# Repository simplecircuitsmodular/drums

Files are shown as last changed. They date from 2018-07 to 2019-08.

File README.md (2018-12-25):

# Drums

## Features
These modules features 6 individually triggered and tuned drum voices in one module. The code was written Jan Ostman. I have chosen to rehost the code here for other's convenience as Jan's hosting method introduced numerous endlines that prevented the code from compiling. Jan's source code can be found here:

[Western Drums, DSP-D8](https://janostman.wordpress.com/2016/01/03/the-dsp-d8-drumchip-source-code/)

[Latin Drums, DSP-L8](https://janostman.wordpress.com/2016/01/04/the-dsp-l8-latin-perc-source-code/)

## Files
### westernDrums_01.ino and latinDrums_01.ino
This is the Arduino code. An ISP header on the board allows the microcontroller to be programmed directly. The code was written by Jan Ostman. The Features section has links to Jan's source code.

### drums_xx.brd and .sch
These are the Eagle files for the PCB. To order PCBs, gerbers need to be generated using a CAM job in Eagle. A free version of Eagle is available that can do this. Both the latin and western drums use the same board, the only difference is the panel and code.

### drumsParts_xx.md
This is the parts list. A Mouser BOM is available at in this file as well.

### westernDrums.ai and latinDrums.ai
This is the panel in Adobe Illustrator format. This can be used to manufacture a panel, which I do with 1/8" acrylic and a laser cutter.

## Updates

### 01.1 30JUL18

Verified design. All functions work, though two issues were found. Added values to Eagle files for resistors and capacitors. Updated .brd to fix ISP issue, though this is currently untested. All signals were rerouted.

### 01 24JUN18
First push to GitHub. Currently this design is untested.

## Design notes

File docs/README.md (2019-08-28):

#### [Latin](#latin) | [Western](#western) | [Buy](#buy)

# Latin

### Overview

Based on the DSP-L8 drum voice chip, this module offers 8 polyphonic drum sounds in a small package. Featuring cabasa, agogo, timbale, whistle, quijada, maraca, congo, and chime sounds, each voice can be triggered individually and the maraca, chime, whistle, agogo, timbale, and quijada can be individually tuned.

### Design

Utilizing an ATMega 328 chip, this module can be easily programmed with the Arduino IDE and an ISP Programmer. A 7805 regulator removes the need for a 5v rail on your PSU, and as an all digital module the current draw is very low. The code used was written by Jan Osterman. I have chosen to rehost Jan's code as his hosting method causes numerous compilation errors.

# Western

### Overview 

Based on the DSP-8 drum voice chip, this module offers 8 polyphonic drum sounds in a small package. Featuring bass, open hat, closed hat, ride, rim shot, snare, clap, and crash sounds, each voice can be triggered individually, and the rim shot, clap, crash, snare, closed hat and open hat can be individually tuned.

### Design 

Utilizing an ATMega 328 chip, this module can be easily programmed with the Arduino IDE and an ISP Programmer. A 7805 regulator removes the need for a 5v rail on your PSU, and as an all digital module the current draw is very low. The code used was written by Jan Osterman. I have chosen to rehost Jan's code as his hosting method causes numerous compilation errors.

### Buy

I'll be updating this part soon with a link to buy PCBs on Reverb. For the time being you can email me to purchase development PCBs at a discount. These will be fully functional but have minor issues. In the case of the Drum PCBs, the programming header must be soldered to the front side of the PCB, meaning the front panel must be removed to program the module. In addition, the back of the board is missing silk screen.

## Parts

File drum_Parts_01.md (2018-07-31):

# Parts List

Mouser BOM: https://www.mouser.com/ProjectManager/ProjectDetail.aspx?AccessID=271197b1ba

| Name | Value | Package | Source |
| --- | --- | --- | --- |
| C1, 2, 6 | 10u | Radial TH | Mouser |
| C3, 4 | 22pf | Radial TH | Mouser |
| C5 | 100n | Radial TH | Mouser |
| IC1 | ATMega 328 | DIP-28 | Mouser |
| IC2 | 7805 | TO220H | Mouser |
| IC3 | TL072 | DIP8 | Mouser |
| R1-3 | 1k | Axial TH | Mouser |
| SV1 | 6 pin header | 2.54mm | Mouser |
| SV2 | 10 pin header | 2.54mm | Mouser |
| U$1-8, 15 | Switched mono jack | Thonkiconn | Modular Addict |
| U$9-14 | Potentiometer, B10k | Alpha 9mm vertical | Mouser |

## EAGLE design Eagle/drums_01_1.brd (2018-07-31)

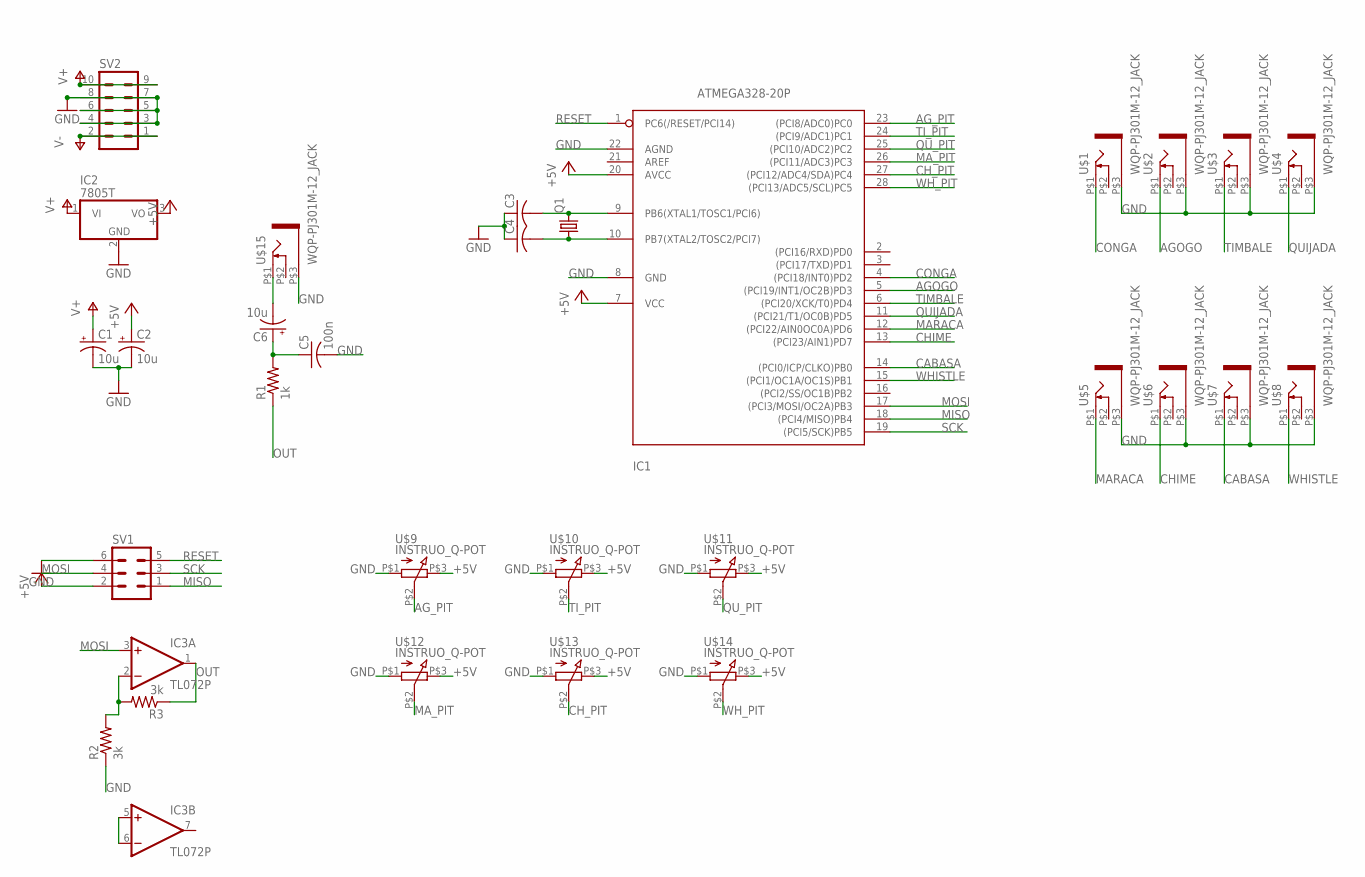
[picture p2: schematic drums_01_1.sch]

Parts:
C1, C2, C6: 10u; E2,5-6
C3, C4: C-US025-024X044; C025-024X044
C5: 100n; C025-024X044
IC1: ATMEGA328-20P; DIL28-3
IC2: 7805T; TO220H
IC3: TL072P; DIL08
Q1: CRYSTALHC49U-V; HC49U-V
R1: 1k; 0207/12
R2, R3: 3k; 0207/12
SV1: MA03-2
SV2: MA05-2
U$1, U$2, U$3, U$4, U$5, U$6, U$7, U$8, U$15: WQP-PJ301M-12_JACK
U$9, U$10, U$11, U$12, U$13, U$14: INSTRUO_Q-POT

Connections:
+5V: C2.+, IC1.7 (VCC), IC1.20 (AVCC), IC2.3 (VO), SV1.2, U$9.P$3 (3), U$10.P$3 (3), U$11.P$3 (3), U$12.P$3 (3), U$13.P$3 (3), U$14.P$3 (3)
AGOGO: IC1.5 ((PCI19/INT1/OC2B)PD3), U$2.P$1 (2)
AG_PIT: IC1.23 ((PCI8/ADC0)PC0), U$9.P$2 (2)
CABASA: IC1.14 ((PCI0/ICP/CLKO)PB0), U$7.P$1 (2)
CHIME: IC1.13 ((PCI23/AIN1)PD7), U$6.P$1 (2)
CH_PIT: IC1.27 ((PCI12/ADC4/SDA)PC4), U$13.P$2 (2)
CONGA: IC1.4 ((PCI18/INT0)PD2), U$1.P$1 (2)
GND: C1.-, C2.-, C3.1, C4.1, C5.2, IC1.8 (GND), IC1.22 (AGND), IC2.2 (GND), R2.1, SV1.6, SV2.3, SV2.4, SV2.5, SV2.6, SV2.7, SV2.8, U$1.P$3 (1), U$2.P$3 (1), U$3.P$3 (1), U$4.P$3 (1), U$5.P$3 (1), U$6.P$3 (1), U$7.P$3 (1), U$8.P$3 (1), U$9.P$1 (1), U$10.P$1 (1), U$11.P$1 (1), U$12.P$1 (1), U$13.P$1 (1), U$14.P$1 (1), U$15.P$3 (1)
MARACA: IC1.12 ((PCI22/AIN0OC0A)PD6), U$5.P$1 (2)
MA_PIT: IC1.26 ((PCI11/ADC3)PC3), U$12.P$2 (2)
MISO: IC1.18 ((PCI4/MISO)PB4), SV1.1
MOSI: IC1.17 ((PCI3/MOSI/OC2A)PB3), IC3.3 (+IN), SV1.4
unnamed: C3.2, IC1.9 (PB6(XTAL1/TOSC1/PCI6)), Q1.2
unnamed: C4.2, IC1.10 (PB7(XTAL2/TOSC2/PCI7)), Q1.1
unnamed: C6.-, U$15.P$1 (2)
unnamed: C5.1, C6.+, R1.2
unnamed: IC3.5 (+IN), IC3.6 (-IN)
unnamed: IC3.2 (-IN), R2.2, R3.2
OUT: IC3.1 (OUT), R1.1, R3.1
QUIJADA: IC1.11 ((PCI21/T1/OC0B)PD5), U$4.P$1 (2)
QU_PIT: IC1.25 ((PCI10/ADC2)PC2), U$11.P$2 (2)
RESET: IC1.1 (PC6(/RESET/PCI14)), SV1.5
SCK: IC1.19 ((PCI5/SCK)PB5), SV1.3
TIMBALE: IC1.6 ((PCI20/XCK/T0)PD4), U$3.P$1 (2)
TI_PIT: IC1.24 ((PCI9/ADC1)PC1), U$10.P$2 (2)
V+: C1.+, IC2.1 (VI), IC3.8 (V+), SV2.9, SV2.10
V-: IC3.4 (V-), SV2.1, SV2.2
WHISTLE: IC1.15 ((PCI1/OC1A/OC1S)PB1), U$8.P$1 (2)
WH_PIT: IC1.28 ((PCI13/ADC5/SCL)PC5), U$14.P$2 (2)

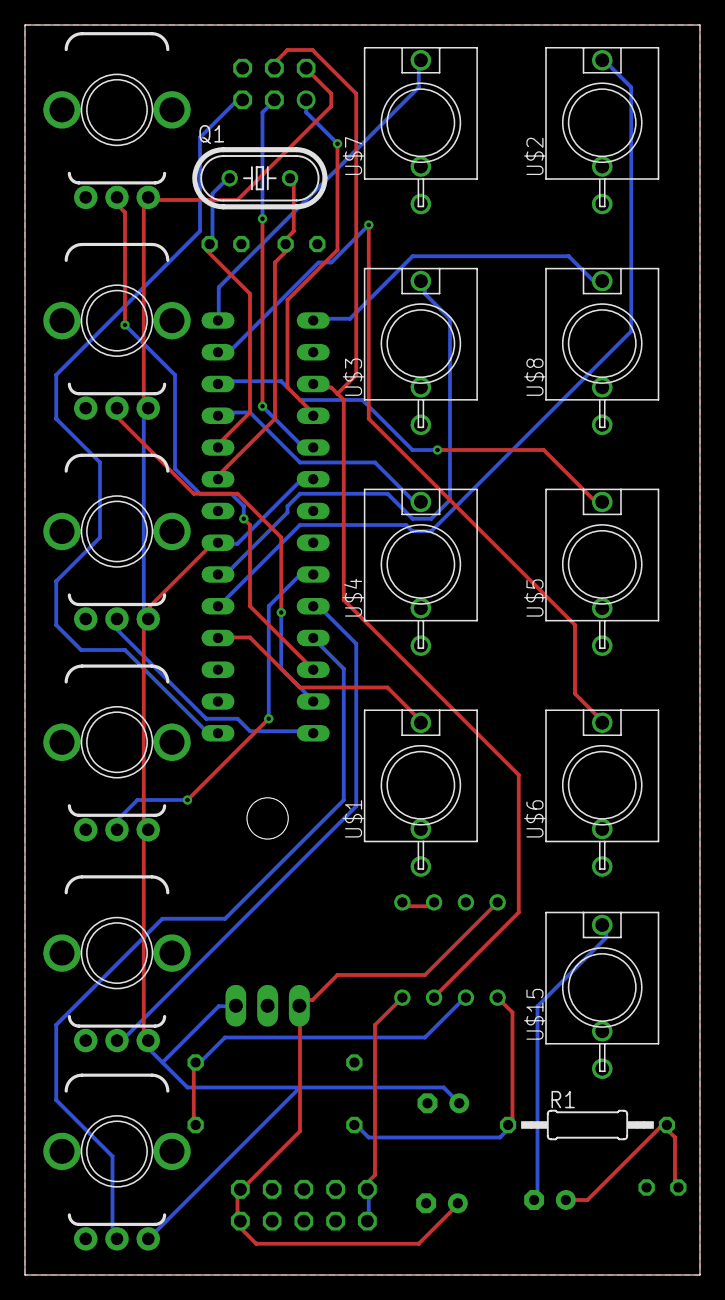
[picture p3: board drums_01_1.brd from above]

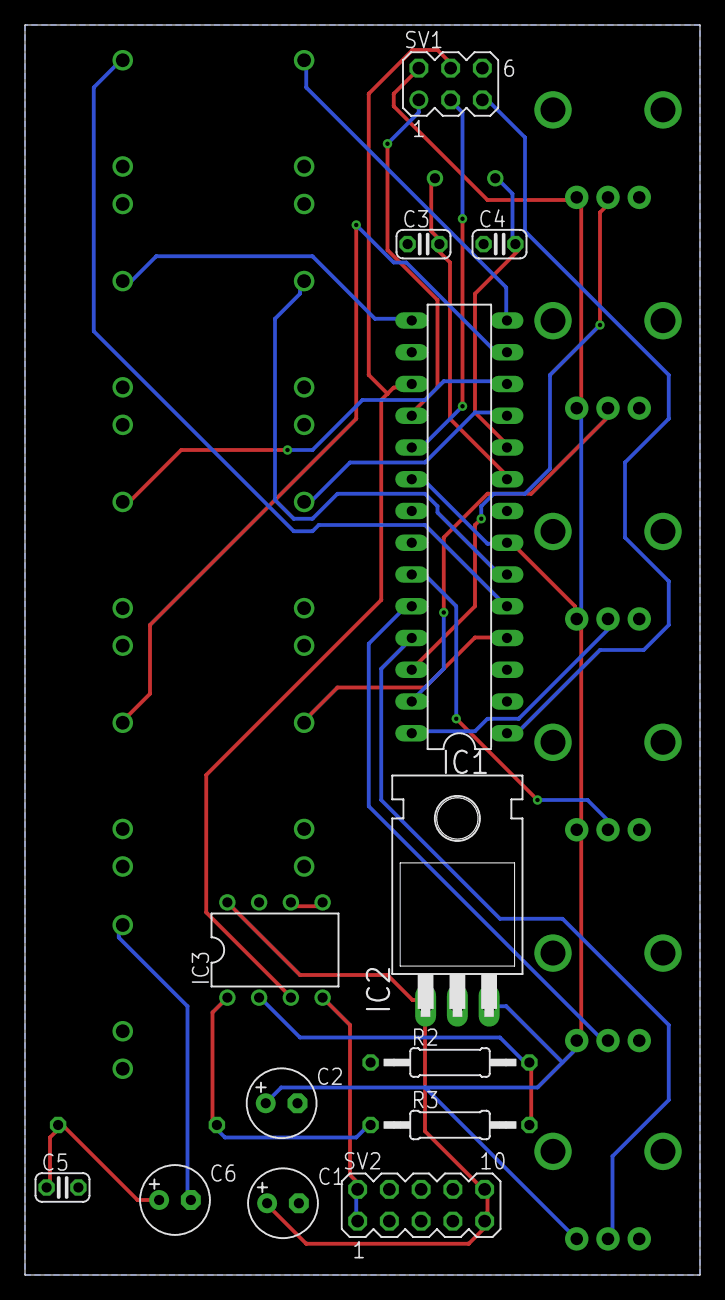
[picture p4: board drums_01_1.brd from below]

Board: 2 copper layers, 54.0 x 100.0 mm, 30 parts (13 on the bottom side), 29 nets.

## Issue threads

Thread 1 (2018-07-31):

Missing Silkscreen

biednick, 2018-07-31:
The silkscreen is missing from the back side of the board. This is likely an issue while generating while generating gerbers for manufacturing. Module can easily be built using the .brd and .sch files for reference.

biednick, 2018-08-09:
Missing silkscreen was caused by an error when generating gerbers

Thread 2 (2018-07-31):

ISP Header Reversed

biednick, 2018-07-31:
The 6 pin ISP header is reversed. The module can be build by solderinf the header so it extends from the front of the board rather than the back, however new firmware cannot be flashed with the panel mounted in this configuration.

biednick, 2018-07-31:
Header redone for version 01.1. Although this is untested, I am confident the issue has been corrected.

Closed 2018-07-31.

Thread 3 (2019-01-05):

Audio triggers on falling edge causing timing issues with gate signals

biednick, 2019-01-05:
The audio output seems to be triggered on the falling edge rather than the rising edge of a trigger or gate. This isn't an issue with devices that use a short trigger pulse as the timing difference is not noticable, but with devices that send longer gate signals (such as the Beatstep Pro) the issue is very noticable.

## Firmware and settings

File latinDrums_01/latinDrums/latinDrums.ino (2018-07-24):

// dsp-L8 Latin Perc Chip (c) DSP Synthesizers 2015
// Free for non commercial use
// Please consider a donation of $3 if you find this code useful
#include <avr/interrupt.h>
#include <avr/io.h>
#include <avr/pgmspace.h>
#ifndef cbi
#define cbi(sfr, bit) (_SFR_BYTE(sfr) &= ~_BV(bit))
#endif
#ifndef sbi
#define sbi(sfr, bit) (_SFR_BYTE(sfr) |= _BV(bit))
#endif
// Standard Arduino Pins
#define digitalPinToPortReg(P) \(((P) >= 0 && (P) <= 7) ? &PORTD : (((P) >= 8 && (P) <= 13) ? &PORTB : &PORTC))
#define digitalPinToDDRReg(P) \(((P) >= 0 && (P) <= 7) ? &DDRD : (((P) >= 8 && (P) <= 13) ? &DDRB : &DDRC))
#define digitalPinToPINReg(P) \(((P) >= 0 && (P) <= 7) ? &PIND : (((P) >= 8 && (P) <= 13) ? &PINB : &PINC))
#define digitalPinToBit(P) \(((P) >= 0 && (P) <= 7) ? (P) : (((P) >= 8 && (P) <= 13) ? (P) - 8 : (P) - 14))
#define digitalReadFast(P) bitRead(*digitalPinToPINReg(P), digitalPinToBit(P))

#define digitalWriteFast(P, V) bitWrite(*digitalPinToPortReg(P),digitalPinToBit(P), (V))
const unsigned char PS_128 = (1 << ADPS2) | (1 << ADPS1) | (1 << ADPS0);
//--------- Ringbuf parameters ----------
uint8_t Ringbuffer[256];
uint8_t RingWrite = 0;
uint8_t RingRead = 0;
volatile uint8_t RingCount = 0;
volatile uint16_t SFREQ;
//-----------------------------------------
const uint8_t AG[1720] PROGMEM =
{
  128, 127, 130, 127, 148, 106, 82, 178, 99, 174, 145, 137, 167, 25, 127, 94, 90, 218, 136, 189, 179, 64, 135, 30, 53, 167, 140, 220, 175, 187, 128, 16, 104, 40, 108, 186, 154, 255, 164, 103, 98, 51, 61, 90, 167, 181, 192, 199, 123, 92, 68, 61, 97, 127, 175, 188, 201, 141, 104, 81, 57, 95, 117, 158, 191, 176, 173, 121, 81, 68, 80, 122, 129, 174, 194, 162, 143, 103, 60, 87, 96, 128, 179, 160, 181, 150, 117, 83, 62, 120, 95, 158, 185, 147, 185, 111, 104, 90, 66, 127, 128, 171, 167, 155, 162, 92, 96, 99, 80, 135, 148, 156, 181, 134, 139, 111, 80, 106, 93, 149, 148, 158, 183, 119, 132, 97, 89, 112, 101, 162, 152, 160, 151, 121, 124, 88, 110, 105, 123, 163, 141, 168, 136, 117, 116, 99, 112, 101, 147, 154, 140, 167, 125, 114, 113, 100, 118, 108, 147, 161, 145, 158, 109, 116, 118, 86, 133, 118, 148, 169, 134, 157, 90, 116, 121, 86, 147, 116, 170, 159, 122, 153, 80, 122, 113, 102, 151, 122, 171, 150, 123, 128, 90, 125, 110, 116, 155, 134, 159, 145, 119, 116, 96, 127, 116, 123, 153, 136, 160, 130, 111, 122, 98, 126, 118, 139, 148, 133, 164, 111, 117, 112, 104, 139, 107, 156, 144, 134, 155, 99, 130, 96, 114, 147, 108, 163, 132, 143, 145, 92, 128, 99, 119, 141, 123, 166, 128, 138, 140, 91, 120, 101, 126, 149, 126, 167, 134, 124, 131, 91, 118, 103, 137, 159, 128, 165, 124, 123, 119, 88, 122, 112, 152, 152, 144, 152, 107, 129, 102, 99, 122, 124, 168, 140, 151, 133, 105, 125, 92, 118, 122, 133, 174, 136, 145, 119, 104, 124, 89, 127, 134, 143, 173, 132, 139, 106, 96, 130, 94, 138, 145, 146, 172, 115, 131, 101, 97, 134, 101, 154, 141, 146, 168, 103, 121, 98, 111, 132, 114, 162, 138, 150, 145, 104, 114, 96, 126, 132, 131, 152, 141, 150, 121, 110, 110, 106, 133, 129, 148, 146, 132, 145, 114, 110, 106, 114, 143, 129, 150, 144, 126, 141, 103, 114, 112, 112, 158, 130, 150, 139, 119, 141, 90, 121, 118, 117, 167, 127, 154, 127, 112, 139, 90, 124, 119, 135, 162, 125, 149, 118, 114, 127, 104, 129, 121, 143, 155, 128, 133, 115, 120, 122, 112, 129, 128, 146, 143, 133, 128, 109, 127, 120, 117, 130, 128, 155, 133, 129, 130, 104, 133, 114, 125, 135, 121, 164, 127, 129, 125, 101, 141, 106, 131, 140, 125, 162, 120, 131, 117, 101, 141, 109, 136, 138, 135, 156, 117, 124, 111, 109, 133, 119, 142, 137, 138, 149, 116, 114, 110, 118, 132, 128, 145, 138, 137, 135, 116, 114, 107, 128, 136, 132, 144, 130, 140, 125, 112, 118, 106, 139, 132, 139, 146, 119, 144, 114, 112, 119, 110, 150, 129, 144, 139, 116, 141, 107, 120, 120, 115, 154, 131, 140, 133, 117, 134, 107, 120, 123, 124, 153, 133, 137, 128, 114, 131, 113, 119, 127, 132, 150, 131, 135, 122, 116, 128, 114, 126, 126, 138, 148, 130, 131, 114, 125, 122, 117, 135, 124, 147, 138, 129, 129, 104, 131, 120, 124, 136, 124, 152, 128, 127, 126, 105, 134, 121, 130, 138, 124, 149, 126, 121, 122, 110, 136, 124, 132, 139, 125, 144, 123, 121, 122, 112, 139, 127, 132, 136, 128, 140, 118, 122, 120, 119, 138, 128, 139, 129, 130, 135, 118, 123, 114, 133, 135, 129, 141, 122, 134, 127, 120, 124, 113, 140, 133, 133, 137, 119, 138, 120, 119, 126, 116, 142, 132, 136, 134, 115, 135, 120, 119, 128, 120, 147, 132, 132, 133, 113, 133, 119, 123, 129, 122, 149, 132, 129, 127, 114, 133, 116, 128, 129, 129, 146, 128, 131, 118, 117, 131, 120, 132, 127, 137, 141, 124, 128, 113, 124, 126, 126, 137, 125, 141, 135, 122, 124, 111, 129, 129, 129, 139, 125, 139, 129, 121, 125, 111, 134, 131, 128, 138, 123, 140, 125, 119, 126, 113, 138, 129, 132, 137, 120, 140, 122, 120, 124, 117, 140, 128, 134, 132, 122, 135, 120, 125, 121, 124, 140, 128, 135, 126, 126, 131, 119, 126, 120, 131, 137, 130, 135, 121, 127, 129, 120, 126, 122, 136, 137, 128, 135, 118, 128, 127, 121, 131, 118, 139, 135, 127, 133, 115, 131, 124, 121, 133, 120, 142, 132, 128, 130, 112, 133, 124, 125, 132, 125, 142, 128, 128, 126, 115, 131, 125, 129, 130, 128, 140, 128, 126, 121, 120, 131, 125, 132, 130, 130, 136, 126, 126, 117, 124, 132, 128, 135, 127, 133, 133, 121, 127, 116, 127, 133, 129, 138, 123, 133, 131, 119, 126, 116, 134, 134, 130, 137, 120, 132, 126, 121, 127, 118, 136, 135, 130, 133, 120, 131, 123, 123, 128, 123, 137, 134, 131, 129, 120, 130, 125, 123, 127, 127, 138, 132, 130, 125, 120, 128, 124, 128, 126, 130, 139, 130, 130, 121, 123, 128, 125, 131, 127, 133, 135, 128, 130, 117, 125, 130, 125, 133, 126, 135, 133, 125, 129, 117, 126, 130, 128, 134, 125, 135, 132, 123, 126, 118, 129, 131, 129, 135, 125, 132, 129, 123, 124, 119, 132, 133, 129, 133, 126, 132, 127, 124, 125, 121, 133, 132, 132, 129, 125, 131, 125, 124, 123, 126, 134, 131, 133, 127, 126, 129, 125, 127, 122, 129, 134, 131, 131, 124, 127, 129, 124, 129, 123, 129, 135, 129, 132, 122, 126, 130, 123, 128, 124, 131, 134, 128, 132, 122, 126, 130, 124, 129, 125, 132, 135, 126, 129, 122, 127, 128, 125, 130, 126, 132, 134, 128, 126, 121, 127, 129, 127, 129, 129, 133, 131, 127, 124, 122, 127, 129, 129, 129, 130, 133, 129, 125, 123, 123, 129, 129, 131, 130, 128, 133, 127, 125, 122, 124, 132, 128, 132, 129, 129, 132, 124, 127, 122, 124, 134, 129, 132, 127, 128, 131, 123, 126, 123, 128, 134, 129, 132, 126, 127, 130, 123, 125, 125, 130, 134, 129, 130, 127, 126, 128, 124, 127, 126, 131, 134, 129, 129, 125, 127, 127, 124, 127, 128, 133, 132, 129, 127, 123, 129, 127, 127, 127, 128, 135, 129, 129, 125, 124, 129, 125, 129, 127, 128, 135, 129, 128, 124, 124, 130, 125, 129, 129, 129, 133, 128, 128, 124, 124, 131, 127, 129, 129, 130, 133, 126, 126, 124, 125, 131, 128, 131, 128, 130, 132, 125, 124, 124, 128, 130, 129, 131, 128, 130, 128, 127, 124, 123, 130, 130, 130, 128, 128, 131, 127, 126, 124, 125, 131, 130, 132, 128, 127, 130, 126, 126, 124, 127, 132, 130, 131, 128, 127, 129, 126, 126, 125, 127, 134, 130, 130, 128, 126, 129, 125, 127, 126, 128, 133, 130, 129, 125, 126, 129, 125, 126, 127, 131, 132, 129, 128, 125, 126, 127, 127, 126, 127, 132, 132, 129, 125, 125, 127, 127, 127, 128, 129, 131, 130, 129, 125, 125, 128, 127, 128, 128, 129, 132, 129, 127, 125, 124, 129, 129, 129, 128, 128, 133, 127, 126, 124, 125, 130, 128, 130, 128, 128, 131, 128, 126, 124, 126, 131, 128, 129, 129, 129, 130, 127, 125, 125, 127, 130, 130, 129, 128, 129, 129, 126, 124, 126, 129, 130, 131, 129, 128, 128, 128, 126, 124, 126, 131, 131, 129, 128, 127, 128, 127, 126, 126, 126, 131, 131, 129, 127, 126, 129, 127, 126, 126, 128, 132, 129, 130, 126, 126, 129, 127, 127, 126, 129, 132, 129, 128, 126, 126, 128, 127, 127, 127, 128, 132, 130, 126, 126, 126, 128, 128, 127, 129, 130, 131, 129, 127, 125, 126, 129, 128, 127, 128, 131, 131, 128, 126, 126, 127, 129, 128, 129, 128, 130, 130, 127, 125, 125, 129, 129, 129, 128, 129, 130, 128, 127, 125, 125, 129, 130, 129, 127, 129, 130, 127, 126, 126, 127, 130, 130, 129, 128, 127, 130, 128, 125, 126, 128, 131, 129, 128, 128, 128, 129, 127, 126, 126, 129, 131, 129, 128, 127, 128, 128, 127, 126, 127, 130, 130, 129, 127, 126, 128, 127, 128, 126, 128, 131, 130, 129, 126, 126, 128, 127, 128, 127, 128, 131, 130, 128, 126, 126, 128, 127, 127, 128, 129, 130, 129, 128, 126, 126, 129, 129, 127, 127, 129, 130, 128, 127, 126, 126, 129, 129, 128, 128, 129, 130, 129, 126, 126, 127, 129, 129, 128, 128, 129, 129, 128, 126, 126, 128, 130, 129, 127, 128, 129, 129, 128, 126, 127, 128, 129, 129, 127, 127, 129, 128, 127, 126, 127, 129, 129, 129, 128, 127, 128, 128, 127, 126, 127, 130, 130, 128, 127, 128, 128, 128, 127, 127, 128, 130, 130, 128, 127, 127, 129, 128, 126, 127, 129, 130, 129, 127, 127, 127, 128, 128, 126, 128, 129, 130, 129, 127, 127, 128, 128, 128, 128, 128, 129, 130, 129, 126, 126, 128, 128, 128, 128, 128, 129, 129, 128, 126, 126, 128, 129, 129, 127, 128, 130, 129, 127, 126, 127, 129, 129, 129, 128, 128, 129, 129, 127, 126, 127, 129, 129, 128, 128, 128, 129, 128, 127, 127, 128, 129, 130, 128, 127, 128, 129, 128, 126, 127, 129, 129, 129, 127, 127, 127, 128, 128, 126, 128, 129, 130, 129, 128, 127, 128, 128, 128, 127, 127, 129, 130, 129, 127, 127, 128, 128, 128, 127, 128, 130, 130, 128, 127, 127, 128, 129, 127, 127, 128, 130, 129, 128, 127, 127, 128, 129, 127, 128, 128, 130, 129, 127, 126, 127, 129, 128, 128, 128, 129, 129, 128, 128, 126, 127, 129, 129, 127, 128, 129, 129, 128, 127, 127, 128, 128, 129, 128, 128, 128, 129, 128, 127, 128, 128, 128, 128, 128, 128, 128, 128, 128, 128, 128, 128, 128, 128, 128, 128, 128, 128, 128, 128, 128, 128, 128, 128, 128, 128, 128, 128, 128, 128, 128, 128, 128, 128, 128, 128, 128, 128, 128, 128, 128, 128, 128, 128, 128, 128, 128, 128, 128, 128, 128, 128, 128, 128, 128, 128, 128, 128, 128, 128, 128, 128, 128, 128, 128, 128, 128, 128, 128, 128, 128, 128, 128, 128, 128, 128, 128, 128, 128, 128, 128, 128, 128, 128, 128, 128, 128, 128, 128, 128, 128, 128, 128, 128
};
const uint8_t CA[2174] PROGMEM =
{
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
void loop() {

  uint8_t phaccAG, phaccCA, phaccMA, phaccWH, phaccTI, phaccCH, phaccQU, phaccBO;
  uint8_t pitchAG = 32;
  uint8_t pitchCA = 64;
  uint8_t pitchMA = 64;
  uint8_t pitchWH = 32;
  uint8_t pitchTI = 64;
  uint8_t pitchCH = 16;
  uint8_t pitchQU = 16;
  uint8_t pitchBO = 64;
  uint16_t samplecntAG, samplecntCA, samplecntMA, samplecntWH, samplecntTI, samplecntCH, samplecntQU, samplecntBO;
  uint16_t samplepntAG, samplepntCA, samplepntMA, samplepntWH, samplepntTI, samplepntCH, samplepntQU, samplepntBO;

  int16_t total;
  uint8_t oldPORTB;
  uint8_t oldPORTD;
  uint8_t divider;
  uint8_t MUX = 0;

  while (1) {
    //------ Add current sample word to ringbuffer FIFO --------------------

    if (RingCount < 255) { //if space in ringbuffer
      total = 0;
      if (samplecntAG) {
        phaccAG += pitchAG;
        if (phaccAG & 128) {
          phaccAG &= 127;
          total += (pgm_read_byte_near(AG + samplepntAG) - 128);
          samplepntAG++;
          samplecntAG--;

        }
      }
      if (samplecntBO) {
        phaccBO += pitchBO;
        if (phaccBO & 128) {
          phaccBO &= 127;
          total += (pgm_read_byte_near(BO + samplepntBO) - 128);
          samplepntBO++;
          samplecntBO--;

        }
      }
      if (samplecntMA) {
        phaccMA += pitchMA;
        if (phaccMA & 128) {
          phaccMA &= 127;
          total += (pgm_read_byte_near(MA + samplepntMA) - 128);
          samplepntMA++;
          samplecntMA--;

        }
      }
      if (samplecntQU) {
        phaccQU += pitchQU;
        if (phaccQU & 128) {
          phaccQU &= 127;
          total += (pgm_read_byte_near(QU + samplepntQU) - 128);
          samplepntQU++;
          samplecntQU--;

        }
      }
      if (samplecntCA) {
        phaccCA += pitchCA;
        if (phaccCA & 128) {
          phaccCA &= 127;
          total += (pgm_read_byte_near(CA + samplepntCA) - 128);
          samplepntCA++;
          samplecntCA--;

        }
      }
      if (samplecntTI) {
        phaccTI += pitchTI;
        if (phaccTI & 128) {
          phaccTI &= 127;
          total += (pgm_read_byte_near(TI + samplepntTI) - 128);
          samplepntTI++;
          samplecntTI--;

        }
      }
      if (samplecntWH) {
        phaccWH += pitchWH;
        if (phaccWH & 128) {
          phaccWH &= 127;
          total += (pgm_read_byte_near(WH + samplepntWH) - 128);
          samplepntWH++;
          samplecntWH--;

        }
      }
      if (samplecntCH) {
        phaccCH += pitchCH;
        if (phaccCH & 128) {
          phaccCH &= 127;
          total += (pgm_read_byte_near(CH + samplepntCH) - 128);
          samplepntCH++;
          samplecntCH--;

        }
      }
      total >>= 1;
      if (!(PINB & 4)) total >>= 1;
      total += 128;
      if (total > 255) total = 255;

      cli();
      Ringbuffer[RingWrite] = total;
      RingWrite++;
      RingCount++;
      sei();
    }
    //----------------------------------------------------------------------------
    //----------------- Handle Triggers ------------------------------
    if (PIND & 4) {
      samplepntBO = 0;
      samplecntBO = 1474;
    }
    if (PIND & 8) {
      samplepntAG = 0;
      samplecntAG = 1720;
    }
    if (PIND & 16) {
      samplepntTI = 0;
      samplecntTI = 3680;
    }
    if (PIND & 32) {
      samplepntQU = 0;
      samplecntQU = 6502;
    }
    if (PIND & 64) {
      samplepntMA = 0;
      samplecntMA = 394;
    }
    if (PIND & 128) {
      samplepntCH = 0;
      samplecntCH = 5596;
    }
    if (PINB & 1) {
      samplepntCA = 0;
      samplecntCA = 2174;
    }
    if (PINB & 2) {
      samplepntWH = 0;
      samplecntWH = 2670;
    }
    //-----------------------------------------------------------------
    //--------------- ADC block -------------------------------------
    if (!(divider++)) {
      if (!(ADCSRA & 64)) {
        uint16_t pitch = ((ADCL + (ADCH << 8)) >> 3) + 1;
        if (MUX == 0) pitchAG = pitch;
        if (MUX == 1) pitchTI = pitch;
        if (MUX == 2) pitchQU = pitch;
        if (MUX == 3) pitchMA = pitch;
        if (MUX == 4) pitchCH = pitch;
        if (MUX == 5) pitchWH = pitch;
        MUX++;
        if (MUX == 6) MUX = 0;
        ADMUX = 64 | MUX; //Select MUX
        sbi(ADCSRA, ADSC); //start next conversation
      }
    }
    //---------------------------------------------------------------

  }
}

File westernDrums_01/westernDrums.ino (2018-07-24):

// dsp-D8 Drum Chip (c) DSP Synthesizers 2015
// Free for non commercial use
// Please consider a donation of $3 if you find this code useful
#include <avr/interrupt.h>
#include <avr/io.h>
#include <avr/pgmspace.h>
#ifndef cbi
#define cbi(sfr, bit) (_SFR_BYTE(sfr) &= ~_BV(bit))
#endif
#ifndef sbi
#define sbi(sfr, bit) (_SFR_BYTE(sfr) |= _BV(bit))
#endif
// Standard Arduino Pins
#define digitalPinToPortReg(P) \(((P) >= 0 && (P) <= 7) ? &PORTD : (((P) >= 8 && (P) <= 13) ? &PORTB : &PORTC))
#define digitalPinToDDRReg(P) \(((P) >= 0 && (P) <= 7) ? &DDRD : (((P) >= 8 && (P) <= 13) ? &DDRB : &DDRC))
#define digitalPinToPINReg(P) \(((P) >= 0 && (P) <= 7) ? &PIND : (((P) >= 8 && (P) <= 13) ? &PINB : &PINC))
#define digitalPinToBit(P) \(((P) >= 0 && (P) <= 7) ? (P) : (((P) >= 8 && (P) <= 13) ? (P) - 8 : (P) - 14))
#define digitalReadFast(P) bitRead(*digitalPinToPINReg(P), digitalPinToBit(P))

#define digitalWriteFast(P, V) bitWrite(*digitalPinToPortReg(P),digitalPinToBit(P), (V))
const unsigned char PS_128 = (1 << ADPS2) | (1 << ADPS1) | (1 << ADPS0);
//--------- Ringbuf parameters ----------
uint8_t Ringbuffer[256];
uint8_t RingWrite = 0;
uint8_t RingRead = 0;
volatile uint8_t RingCount = 0;
volatile uint16_t SFREQ;
//-----------------------------------------
const uint8_t BD[2154] PROGMEM =
{
128,128,128,128,128,128,128,127,127,127,127,127,127,127,127,127,127,127,127,127,126,126,126,126,126,126,126,126,126,125,125,125,125,124,124,124,124,123,123,121,119,84,61,59,53,54,53,55,55,58,58,60,61,62,63,64,65,67,68,69,71,72,73,75,76,78,79,81,82,83,85,87,88,89,91,92,94,96,99,105,115,129,145,162,178,191,203,214,222,227,231,233,233,232,230,229,228,226,225,224,222,221,219,218,217,215,214,212,211,210,208,207,206,204,203,201,200,199,198,196,195,194,192,191,190,189,188,186,185,184,182,181,180,178,177,174,171,167,161,154,147,138,130,121,111,101,91,82,73,64,57,51,47,43,40,38,37,35,35,36,38,39,40,42,43,45,46,48,49,51,52,54,55,57,58,59,61,62,64,65,66,68,69,70,71,73,74,75,76,77,79,80,81,82,83,85,86,87,88,89,90,92,93,94,95,96,98,99,100,102,104,108,112,118,124,131,138,146,155,163,172,180,188,195,201,207,213,218,222,225,228,230,231,232,232,233,232,231,229,228,226,225,223,222,220,218,217,215,214,212,210,209,207,206,204,203,201,200,198,197,195,194,193,192,190,189,187,186,185,183,182,181,180,178,177,176,175,174,172,171,170,169,168,167,166,164,163,162,161,160,159,158,157,156,156,155,154,153,152,151,150,149,148,148,147,146,145,144,144,143,142,141,141,140,139,138,138,137,136,135,134,132,129,127,124,120,117,113,109,104,99,94,90,85,79,74,70,64,59,54,49,44,40,36,32,29,26,23,21,19,17,16,15,15,14,14,14,14,15,15,15,16,16,17,18,20,22,23,25,27,29,31,32,34,36,37,39,41,42,44,46,47,49,50,52,54,55,56,58,59,61,62,64,65,66,68,69,70,72,73,74,76,77,78,79,81,82,83,84,85,87,88,89,90,91,92,94,95,96,97,99,100,101,102,103,104,105,106,108,109,110,111,112,113,114,115,116,117,118,119,120,121,121,122,123,124,125,126,127,128,129,130,130,131,132,133,134,134,135,136,137,137,138,139,140,141,142,142,144,146,150,154,158,163,168,173,179,184,189,194,200,205,209,214,218,222,226,230,233,236,238,240,242,243,244,245,246,246,246,246,245,245,244,243,241,240,238,237,235,233,231,230,228,226,225,223,221,220,218,217,215,213,212,211,209,207,206,204,203,201,200,198,197,196,194,193,192,190,189,188,186,185,184,183,182,180,179,178,177,176,174,173,172,171,170,169,168,167,166,165,164,163,162,161,160,159,158,157,156,155,154,153,153,152,151,150,149,148,148,147,146,145,144,144,143,142,141,140,140,139,138,138,137,136,136,135,134,134,133,133,132,131,131,130,130,129,128,128,127,127,126,126,125,125,124,124,123,123,122,122,121,121,120,120,119,119,118,118,117,117,117,116,115,115,114,113,112,111,110,108,106,104,102,99,97,94,91,88,84,81,77,74,70,66,62,58,54,50,46,42,38,35,31,28,25,22,19,16,14,11,9,8,6,5,4,4,3,3,3,3,4,4,4,5,6,7,7,8,9,10,11,12,13,15,16,17,19,21,22,24,26,28,30,31,33,35,37,39,40,42,44,46,48,49,51,53,55,56,58,59,61,62,64,65,67,68,70,71,73,75,76,78,79,81,82,84,85,87,88,90,91,92,94,95,96,98,99,100,101,103,104,105,107,108,109,110,112,113,114,115,116,117,118,119,120,121,122,123,124,125,126,127,128,129,130,130,131,132,133,134,135,135,136,137,138,139,140,140,141,142,143,143,144,145,145,146,147,148,148,149,149,150,151,151,152,152,153,153,154,155,155,156,156,157,157,158,158,159,159,160,160,161,161,162,162,162,163,163,164,164,165,165,166,166,167,168,169,173,177,182,187,192,197,202,207,212,217,221,225,229,233,237,240,243,245,248,249,251,252,253,253,253,253,253,253,252,252,251,250,248,247,245,243,241,240,238,236,234,232,231,229,228,226,224,222,220,219,217,215,214,212,210,209,207,206,204,203,201,200,198,197,195,194,192,191,189,188,187,186,184,183,182,181,179,178,177,176,174,173,172,170,169,168,167,166,165,164,163,162,161,160,159,158,157,156,155,154,153,152,151,150,149,148,148,147,146,145,144,143,143,142,141,140,140,139,138,137,137,136,135,135,134,134,133,132,132,131,130,130,129,128,128,127,127,126,125,125,124,124,123,123,122,122,122,121,121,120,120,119,119,119,118,118,117,117,116,116,116,115,115,114,114,113,113,113,112,112,111,111,110,110,109,109,109,108,107,106,105,103,101,99,97,95,93,90,88,85,82,78,75,71,68,64,60,56,52,48,44,41,37,34,30,27,24,21,18,15,13,10,8,6,5,4,2,2,1,1,1,1,1,2,2,3,4,4,5,6,7,8,9,10,12,13,14,15,17,18,20,21,23,25,27,29,31,33,35,36,38,40,42,44,45,47,49,51,53,54,56,58,60,61,63,64,66,68,70,71,73,74,76,78,79,81,82,84,86,87,88,90,91,93,94,96,97,98,100,101,102,104,105,106,107,109,110,111,112,114,114,116,117,118,119,120,121,122,123,124,125,126,127,128,129,130,131,131,132,133,134,135,136,136,137,138,139,139,140,141,141,142,143,143,144,145,145,146,147,148,148,149,149,150,151,151,152,152,153,153,154,154,155,155,156,156,157,157,158,158,159,159,159,160,160,161,161,162,162,163,163,163,164,164,164,165,165,165,166,166,166,166,167,167,168,168,169,170,173,178,182,187,193,198,203,207,212,217,222,226,230,233,237,240,243,245,247,248,250,250,251,251,251,251,250,250,249,248,247,245,244,242,240,239,237,235,233,231,230,228,226,225,223,221,219,218,216,214,212,211,209,208,206,204,203,201,200,198,197,195,193,192,191,189,188,186,185,184,182,181,180,178,177,176,175,173,172,171,170,168,167,166,165,164,163,162,161,160,159,158,156,156,155,154,152,152,151,150,149,148,147,146,145,144,143,142,142,141,140,139,138,138,137,136,135,135,134,133,133,132,131,131,130,129,129,128,127,126,126,125,124,124,123,123,122,122,121,121,120,120,119,119,118,118,117,117,116,116,115,115,114,114,113,113,112,112,111,110,109,108,107,106,105,104,102,102,100,99,98,97,95,94,92,91,89,87,86,84,82,80,78,76,74,72,70,68,66,63,61,59,57,55,53,51,49,47,46,44,42,40,39,38,36,35,33,32,31,30,29,28,27,27,26,25,25,25,25,24,24,24,24,25,25,25,25,26,26,27,27,28,29,29,30,31,32,33,34,35,36,37,38,39,40,41,42,44,45,46,47,49,50,51,52,53,54,56,57,58,59,60,62,63,64,65,67,68,69,70,72,73,74,75,77,78,79,80,82,83,84,85,86,88,89,90,91,93,94,95,96,98,98,100,101,102,103,104,105,106,108,109,110,111,112,113,114,115,116,117,118,119,120,121,122,123,124,125,126,127,127,128,129,130,131,132,133,134,135,136,137,138,139,140,141,142,143,144,14
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
